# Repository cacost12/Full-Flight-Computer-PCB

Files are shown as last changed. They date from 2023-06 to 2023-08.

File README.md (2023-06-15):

<h1>Full Feature Flight Computer</h1>

<p><b>Current PCB Revision:</b> 1.0</p>
<p><b>PCB Part Number:</b> A0002</p>

<p>
The full feature flight computer supports the full range of amateur rocketry recovery and launch configurations 
such as dual-deploy parachute recovery, staging, IMU and barometric pressure sensor data logging, and redundant
parachute ejection. In addition to all the functionality of the base flight computer model, the full feature 
board includes two IMUs for low and high G data collection, and two auxiliary ignition ports for use with staging
ignition and/or redunant parachute ejection charges. 
 </p>

<b>Working Directory Structure:</b>
 
 <p>
cad: 3d models

doc: documentation

img: images of circuit/footprints for github display 
    
lib: libraries for schematic symbols and footprints
 
production: files needed for pcb fabrication, e.g. gerbers, profile, drill fi    le
 
sim: simulation files 
   
src: source design files, e.g. schematic and board files
 </p>

<h2>3D Model: </h2>
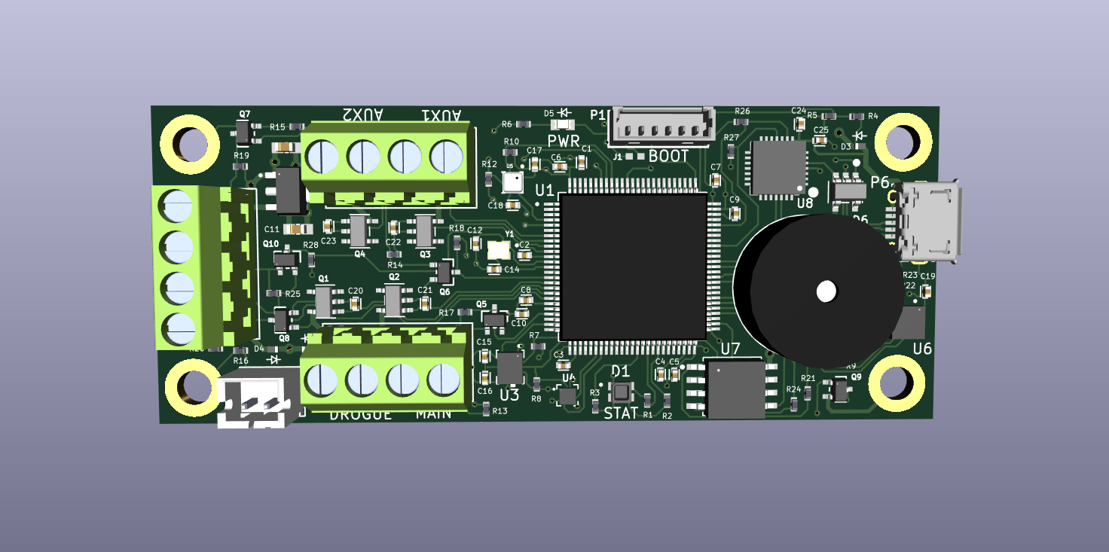
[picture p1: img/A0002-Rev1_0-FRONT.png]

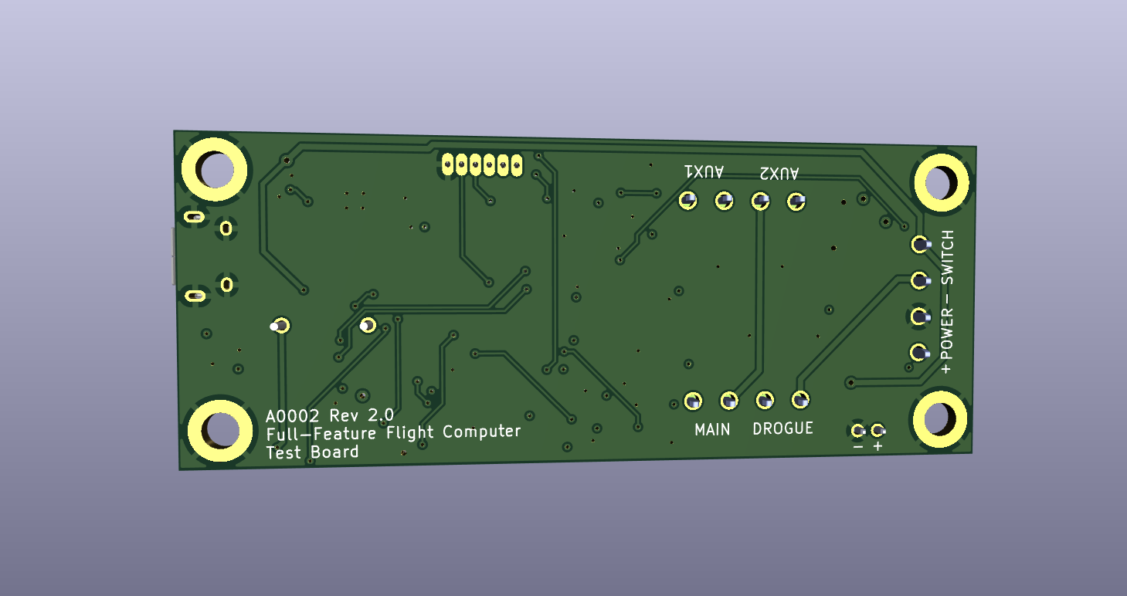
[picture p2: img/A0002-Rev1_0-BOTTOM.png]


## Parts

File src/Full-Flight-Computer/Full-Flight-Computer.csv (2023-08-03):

# | Reference | Qty | Value | Footprint | DNP
1 | BZ1 | 1 | AT-1438-TWT-R | Full-Flight-Computer:AT-1438-TWT-R
2 | C1 | 1 | 4.7uF | Full-Flight-Computer:CAP_0402
3 | C2, C3, C5, C6, C7, C8, C15, C16, C17, C18, C19, C25 | 12 | 0.1uF | Full-Flight-Computer:CAP_0402
4 | C4, C9 | 2 | 2.2uF | Full-Flight-Computer:CAP_0402
5 | C10, C20, C21, C22, C23, C24 | 6 | 1uF | Full-Flight-Computer:CAP_0402
6 | C11, C13 | 2 | 1uF | Full-Flight-Computer:CAP_0603
7 | C12, C14 | 2 | 8pF | Full-Flight-Computer:CAP_0402
8 | D1 | 1 | CLMVC-FKA-CL1D1L71BB7C3C3 | Full-Flight-Computer:CLMVC-FKA-CL1D1L71BB7C3C3
9 | D2, D3, D4 | 3 | PMEG3010AESBYL | Full-Flight-Computer:PMEG3010AESBYL
10 | D5 | 1 | LTST-C191KGKT | Full-Flight-Computer:LTST-C191KGKT
11 | D6 | 1 | SP0504BAHTG | Full-Flight-Computer:SP0504BAHTG
12 | H1, H2 | 2 | Mounting-Hole-4-40 | Full-Flight-Computer:MountingHole_4-40
13 | H3, H4 | 2 | Mounting-Hole | Full-Flight-Computer:MountingHole_4-40
14 | J1 | 1 | Jumper_NO | Full-Flight-Computer:Jumper-NO
15 | P1 | 1 | 0530470610 | Full-Flight-Computer:53047-0610
16 | P2 | 1 | B2B-PH-K-SLFSN_JST | Full-Flight-Computer:B2B-PH-K-SLFSN_JST
17 | P3, P5 | 2 | 1984659 | Full-Flight-Computer:1546551-4
18 | P4 | 1 | 1546551-4 | Full-Flight-Computer:1546551-4
19 | P6 | 1 | USB | Full-Flight-Computer:10118194-0001LF
20 | Q1, Q2, Q3, Q4 | 4 | QS5U17TR | Full-Flight-Computer:QS5U17TR
21 | Q5, Q6, Q7, Q8, Q9, Q10 | 6 | 2N7002W-7-F | Full-Flight-Computer:2N7002W-7-F
22 | R1, R2 | 2 | 82 | Full-Flight-Computer:RES_0402
23 | R3, R6 | 2 | 240 | Full-Flight-Computer:RES_0402
24 | R4 | 1 | 39k | Full-Flight-Computer:RES_0402
25 | R5, R7, R8, R9, R11, R17, R18, R19, R20, R21, R24, R27, R28 | 13 | 10k | Full-Flight-Computer:RES_0402
26 | R10, R12, R26 | 3 | 4.7k | Full-Flight-Computer:RES_0402
27 | R13, R14, R15, R16, R22, R25 | 6 | 100k | Full-Flight-Computer:RES_0402
28 | R23 | 1 | 200k | Full-Flight-Computer:RES_0402
29 | U1 | 1 | STM32H750VBTx | Full-Flight-Computer:STM32H750VBT6
30 | U2 | 1 | AP7370-33Y-13 | Full-Flight-Computer:AP7370-33Y-13
31 | U3 | 1 | BMI323 | Full-Flight-Computer:BMI323
32 | U4 | 1 | BMM150 | Full-Flight-Computer:BMM150
33 | U5 | 1 | BMP390 | Full-Flight-Computer:BMP390
34 | U6 | 1 | H3LIS100DLTR | Full-Flight-Computer:H3LIS100DLTR
35 | U7 | 1 | SST25VF040B-50-4I-S2AE-T | Full-Flight-Computer:SST25VF040B-50-4I-S2AE-T
36 | U8 | 1 | CP2102-GMR(QFN28) | Full-Flight-Computer:CP2012-GMR
37 | Y1 | 1 | ECS-240-18-33-JGN-TR | Full-Flight-Computer:ECS-240-12-37B-CKY-TR

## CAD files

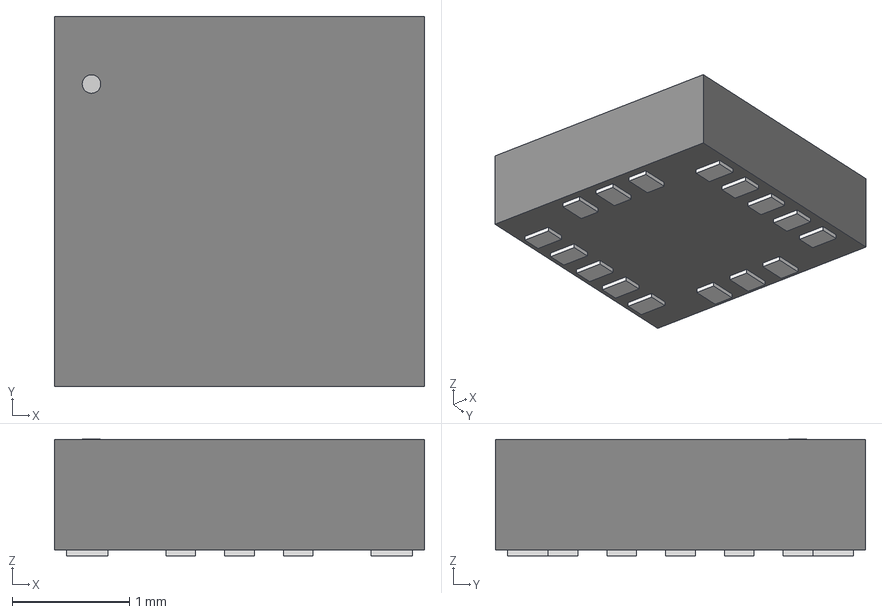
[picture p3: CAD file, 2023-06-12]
CAD/3Dfiles/H3LIS100DLTR.step
3.15 x 3.15 x 0.993 mm

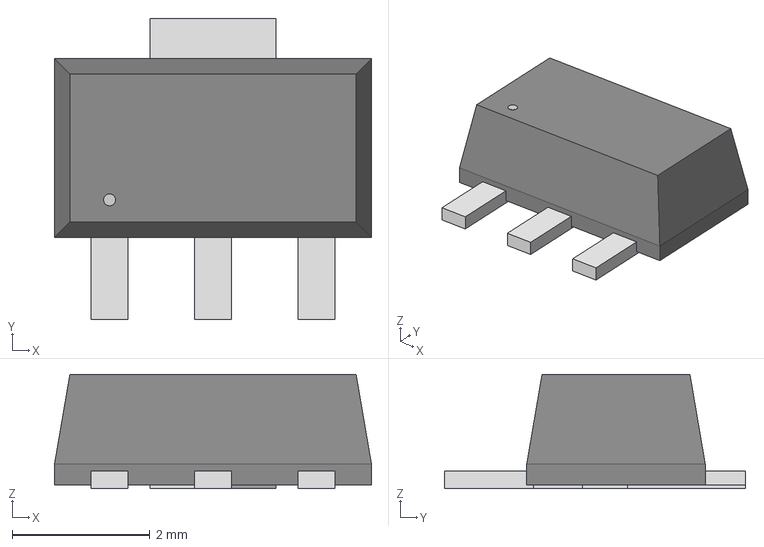
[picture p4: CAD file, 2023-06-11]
CAD/3Dfiles/AP7370-33Y-13.step
4.60 x 4.37 x 1.65 mm

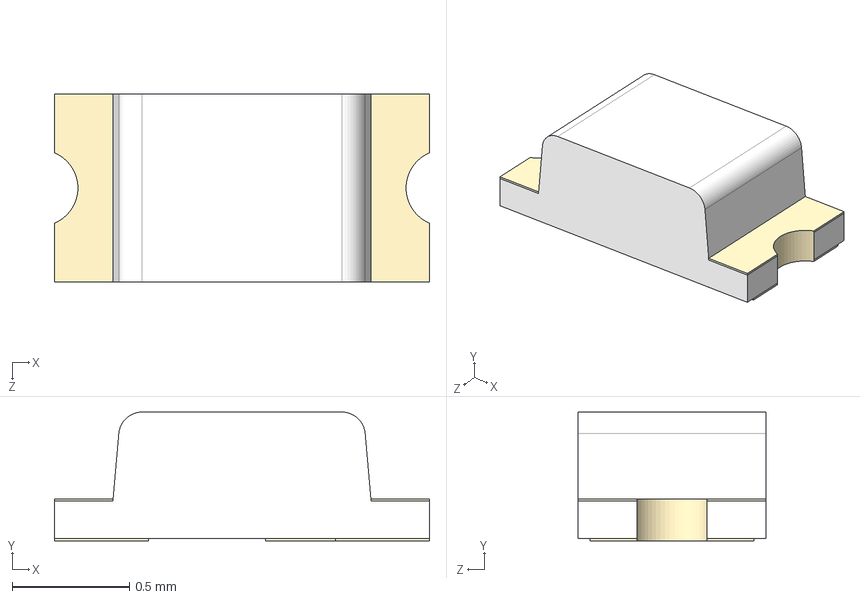
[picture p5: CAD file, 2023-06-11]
CAD/3Dfiles/LTST-C191KGKT.step
1.60 x 0.55 x 0.8 mm

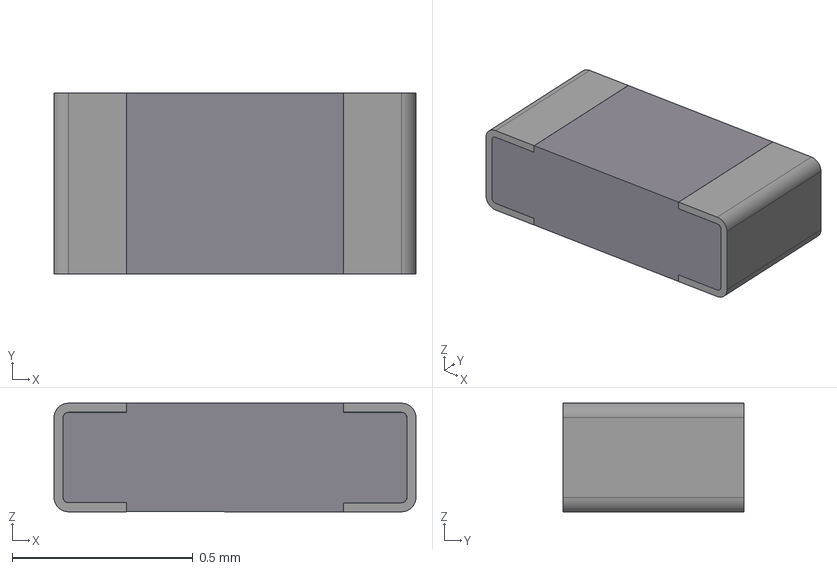
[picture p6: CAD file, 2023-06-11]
CAD/3Dfiles/RES_0402.step
1.00 x 0.5 x 0.3 mm
Chip_001

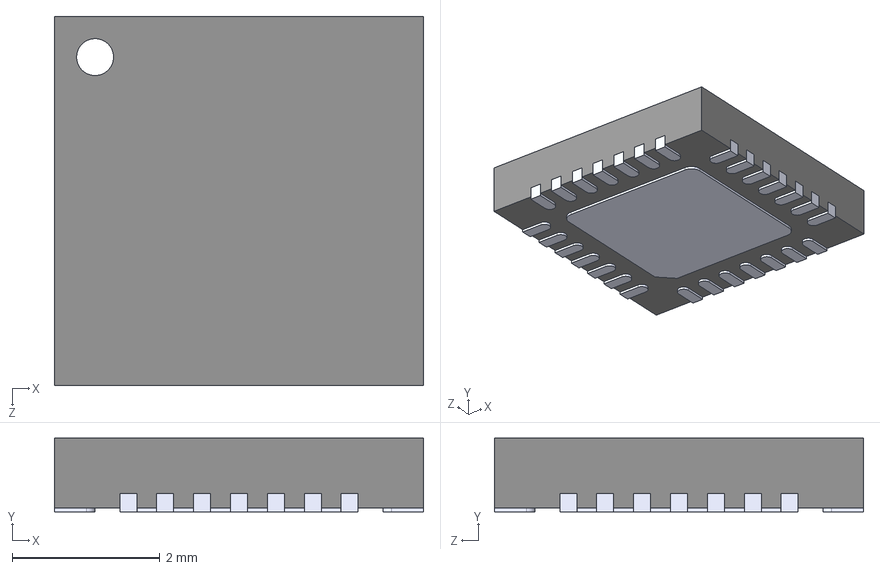
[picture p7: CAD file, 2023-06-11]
CAD/3Dfiles/CP2102.step
5.00 x 1.00 x 5.00 mm

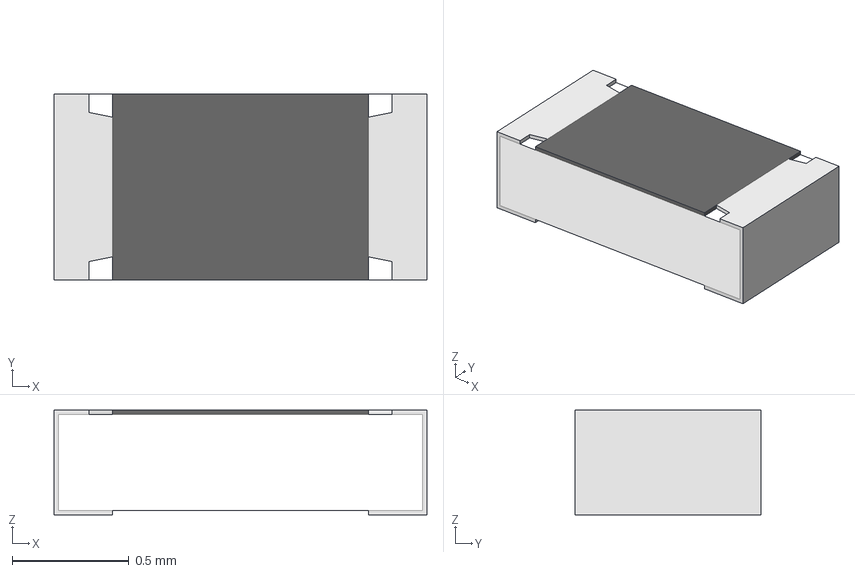
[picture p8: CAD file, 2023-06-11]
CAD/3Dfiles/RES_0603.step
1.60 x 0.8 x 0.45 mm

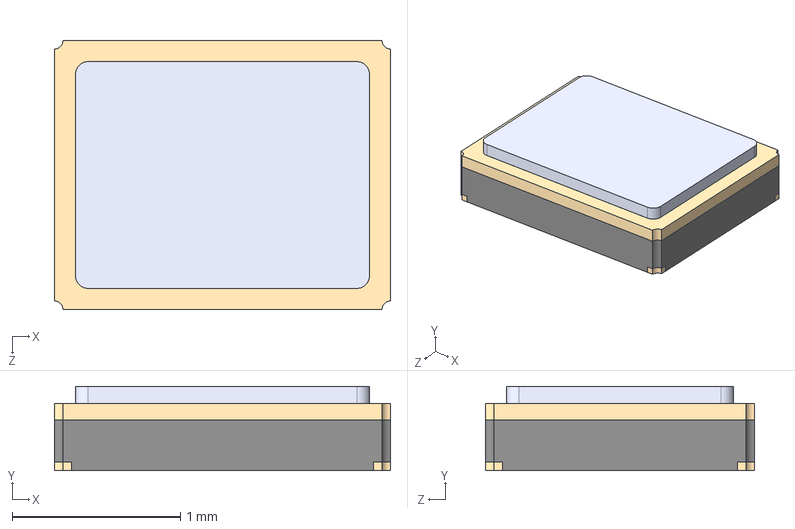
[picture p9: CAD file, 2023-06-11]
CAD/3Dfiles/ECS-240-12-37B-CKY-TR.step
2.00 x 0.5 x 1.60 mm

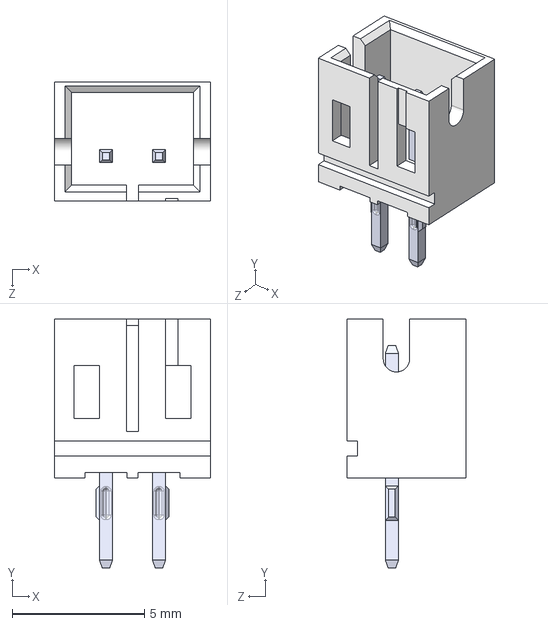
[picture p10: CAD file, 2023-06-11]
CAD/3Dfiles/B2B_PH_K_S_LF__SN_.step
5.90 x 9.40 x 4.50 mm

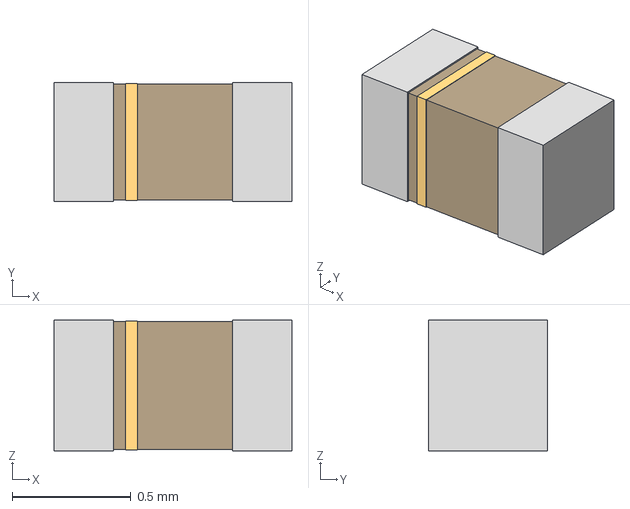
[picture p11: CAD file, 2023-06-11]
CAD/3Dfiles/CAP_0402.step
1.00 x 0.5 x 0.55 mm

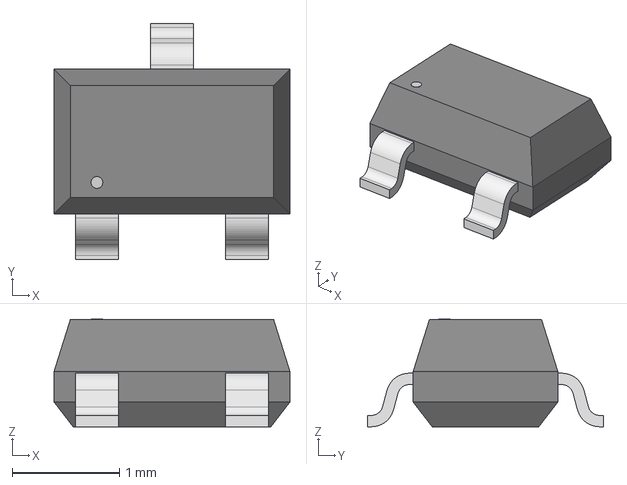
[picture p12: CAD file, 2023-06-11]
CAD/3Dfiles/2N7002W-7-F.step
2.20 x 2.20 x 1.00 mm

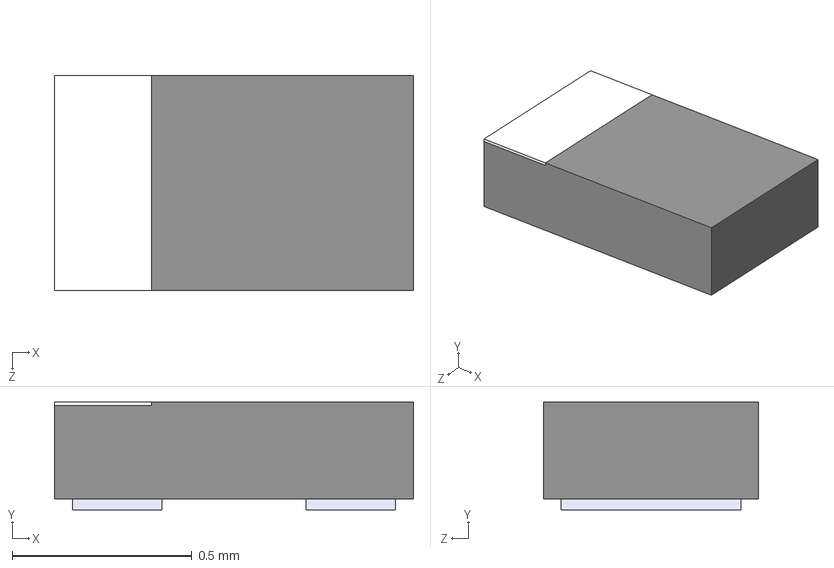
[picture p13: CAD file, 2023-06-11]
CAD/3Dfiles/PMEG3010AESBYL.step
1.00 x 0.3 x 0.6 mm

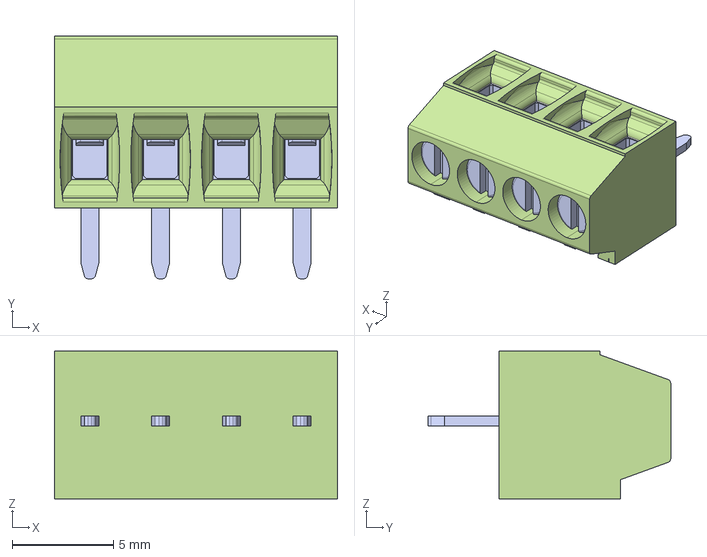
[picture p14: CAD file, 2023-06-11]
CAD/3Dfiles/1546551-4.step
14.0 x 12.0 x 7.30 mm

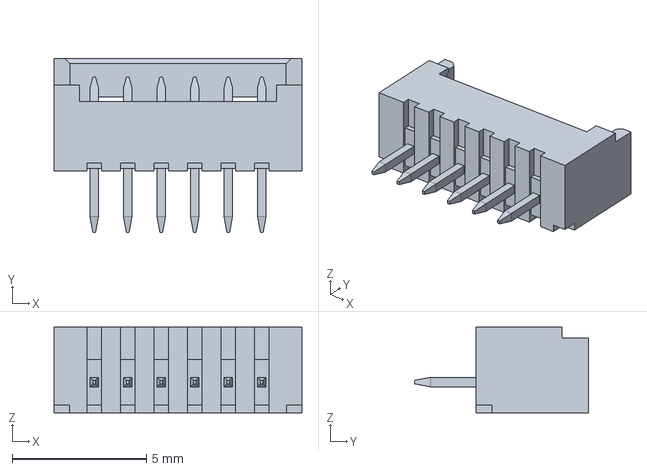
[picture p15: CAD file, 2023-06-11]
CAD/3Dfiles/530470610.stp
9.25 x 6.50 x 3.20 mm

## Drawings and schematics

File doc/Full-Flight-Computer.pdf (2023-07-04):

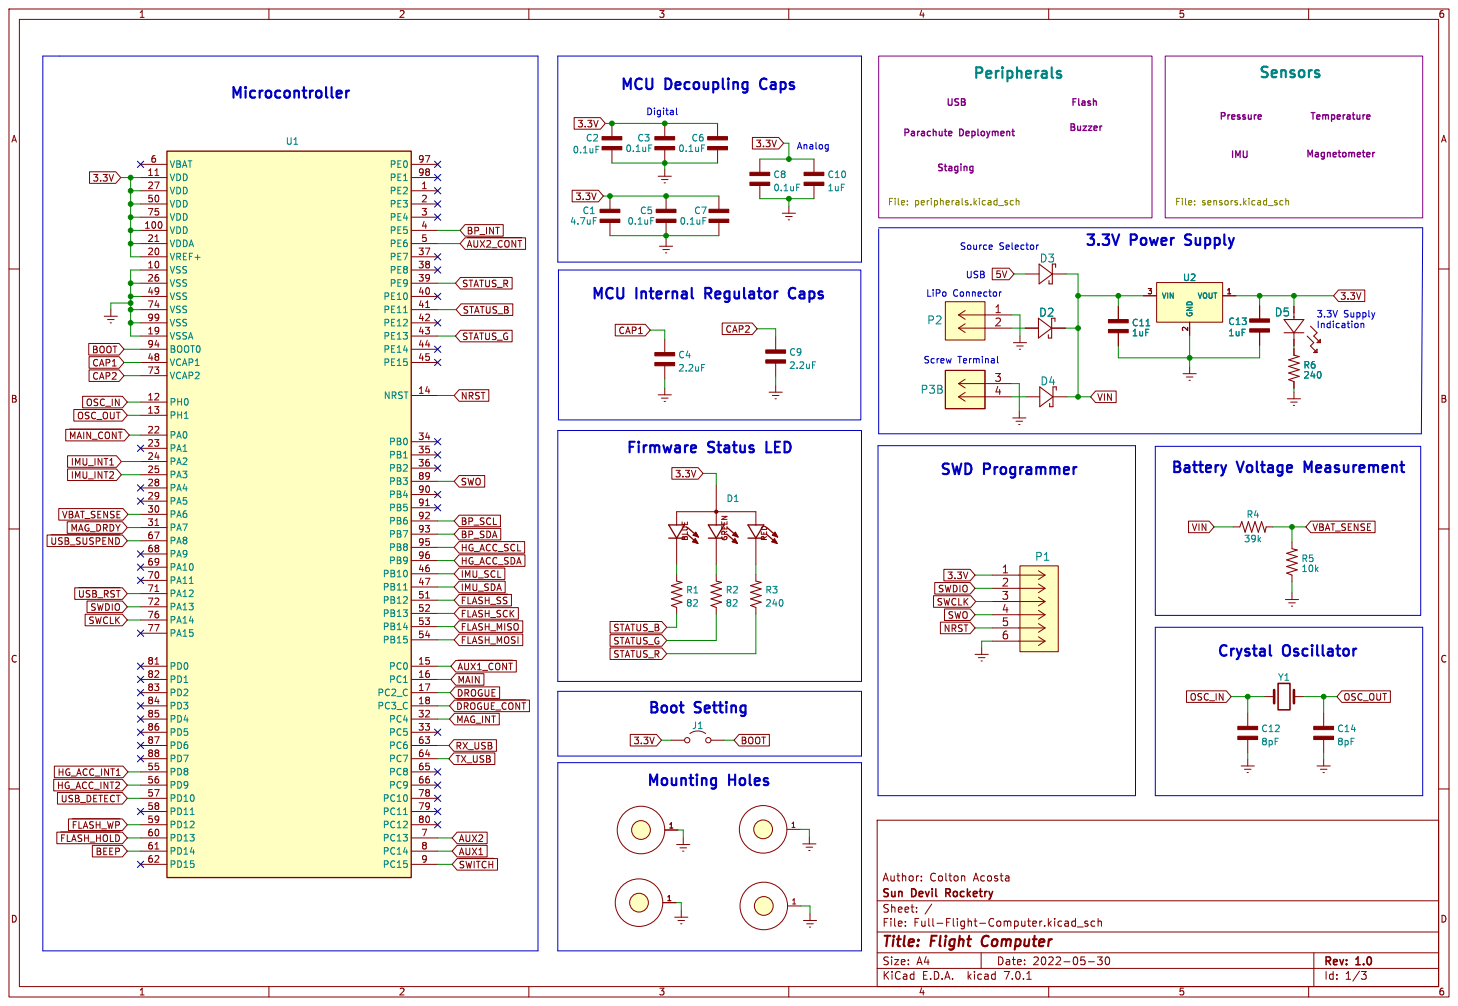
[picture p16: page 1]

Indication Battery Voltage Measurement USB

MCU Internal Regulator Caps

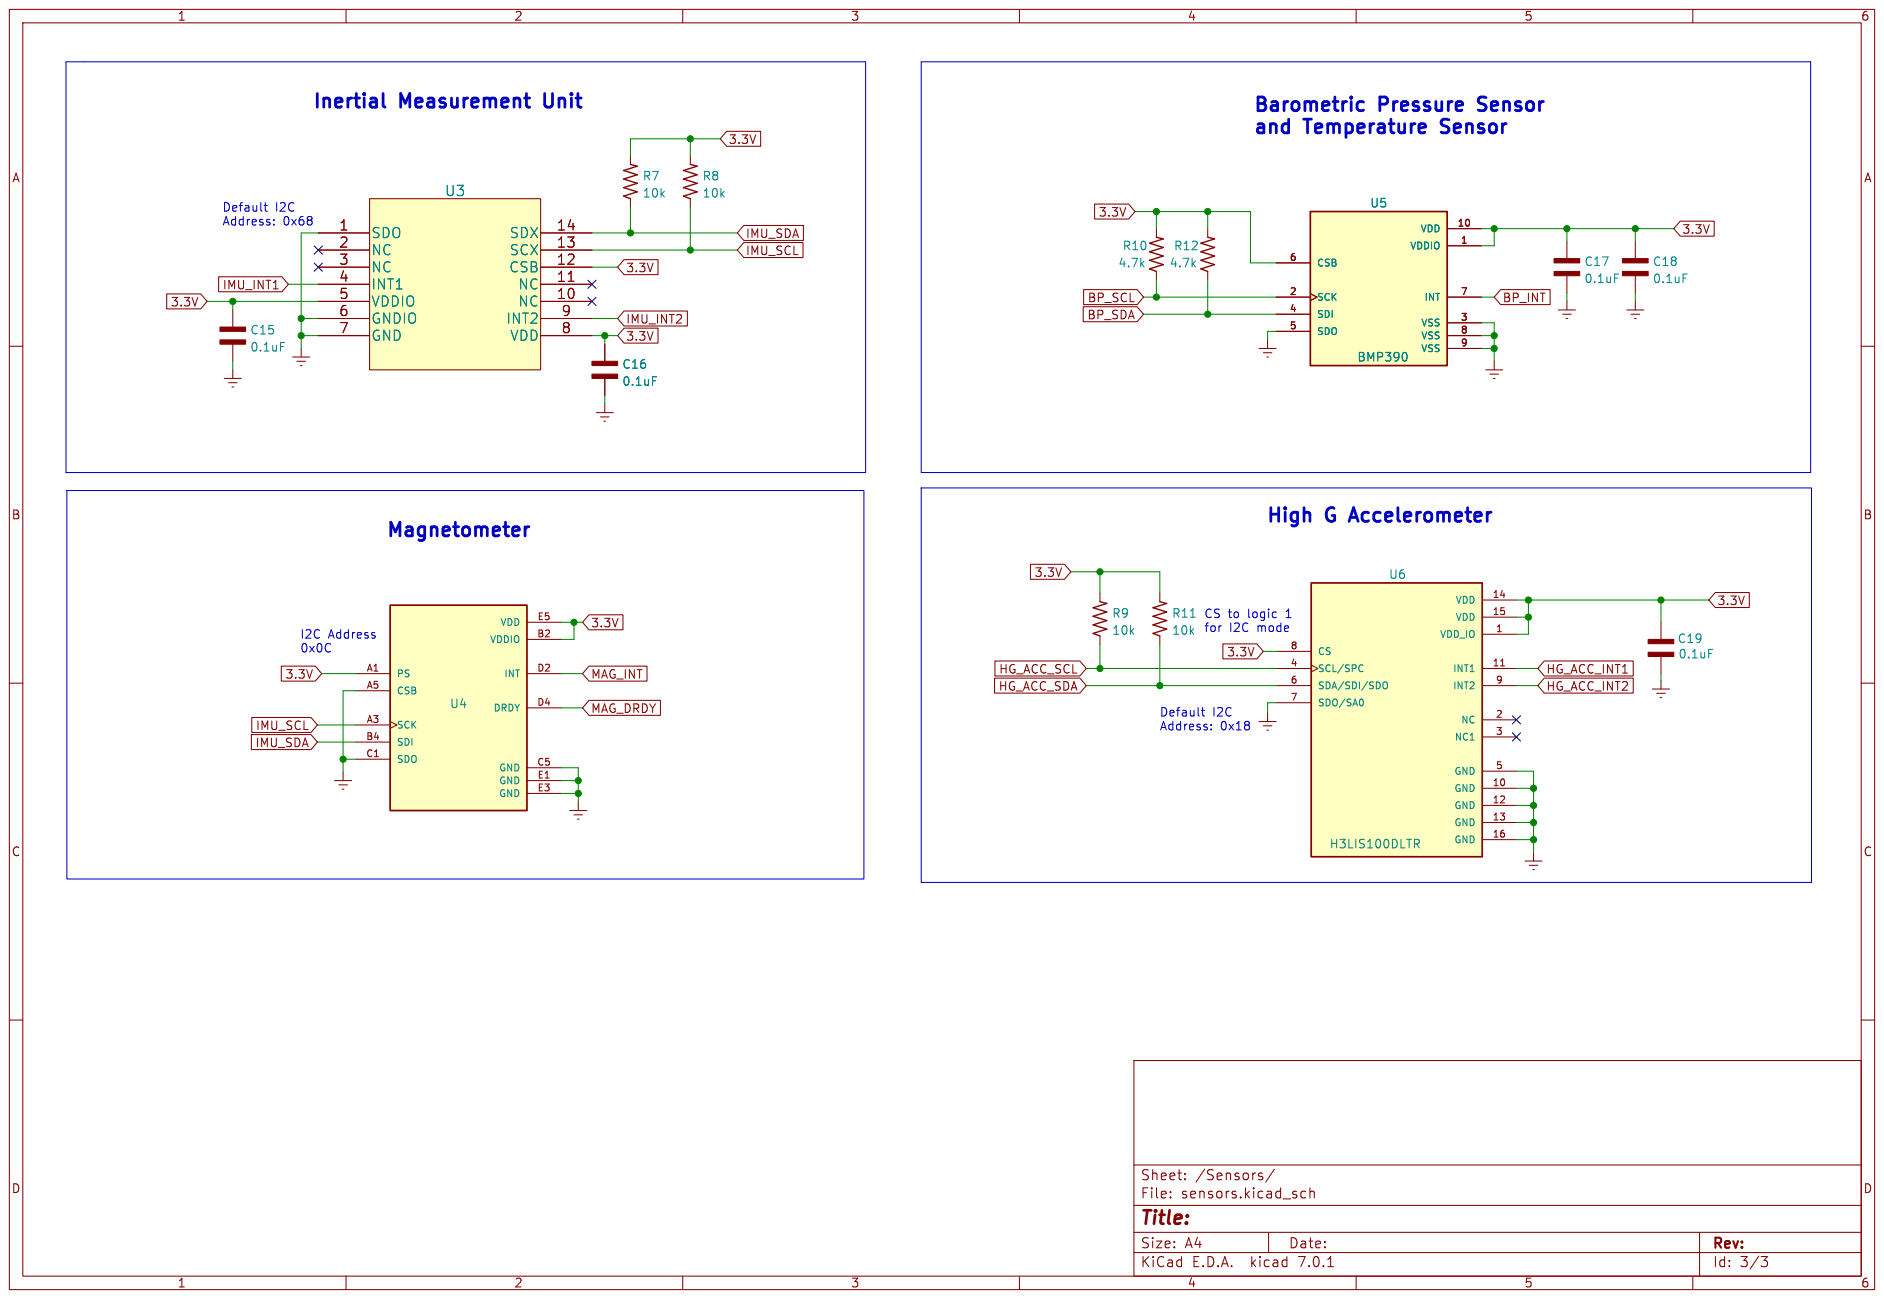
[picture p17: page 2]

Id: 3/3 Title: File: sensors.kicad_sch Sheet: /Sensors/

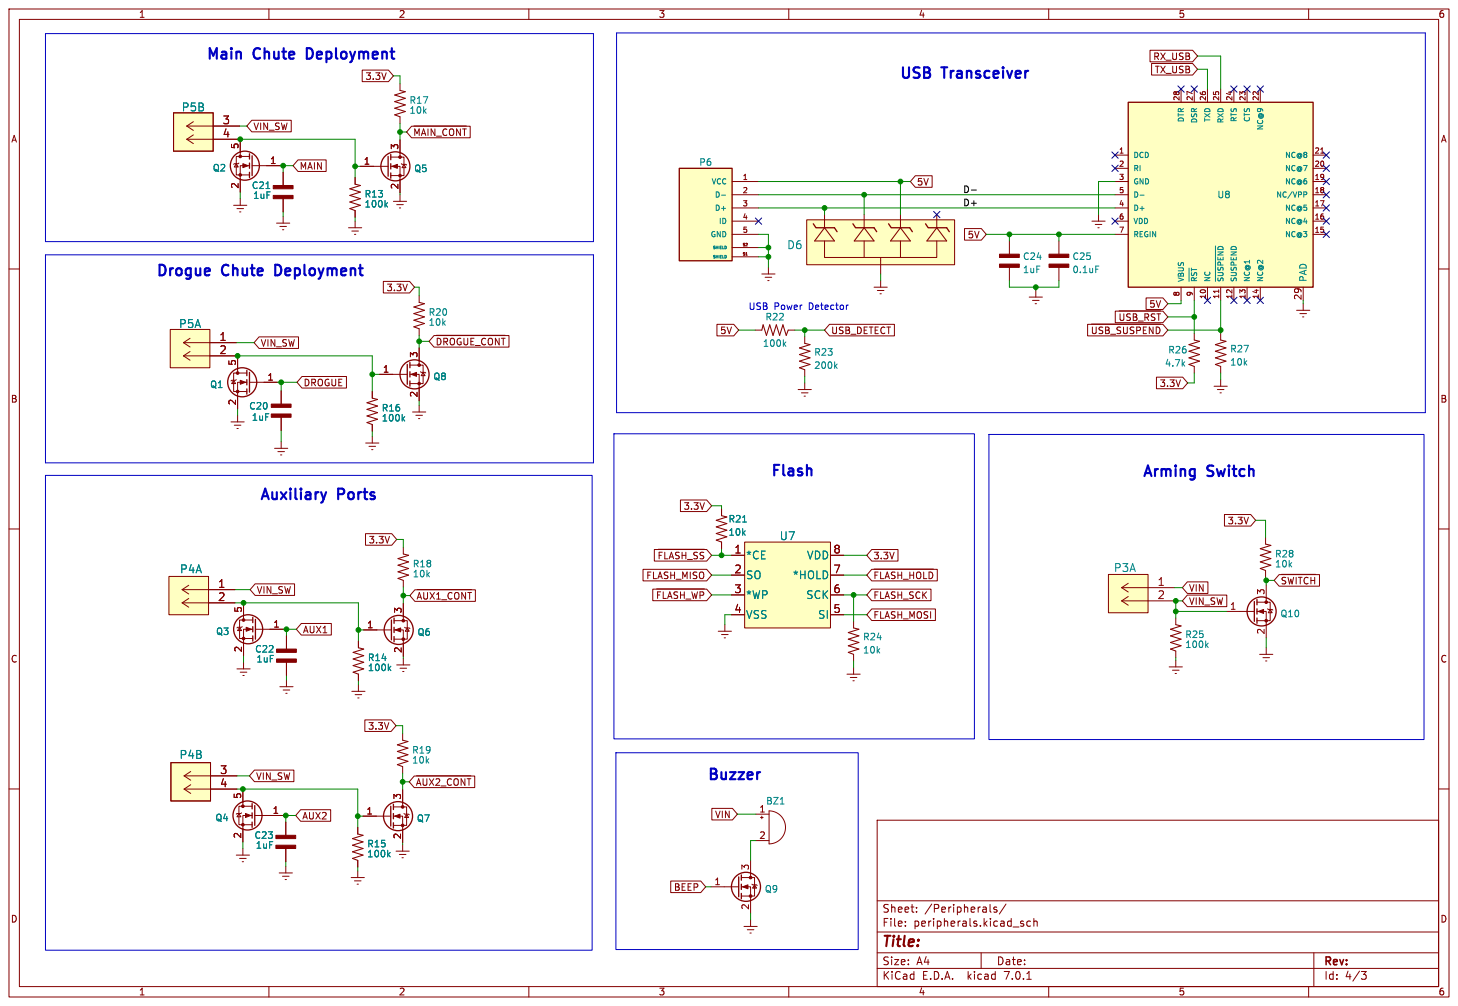
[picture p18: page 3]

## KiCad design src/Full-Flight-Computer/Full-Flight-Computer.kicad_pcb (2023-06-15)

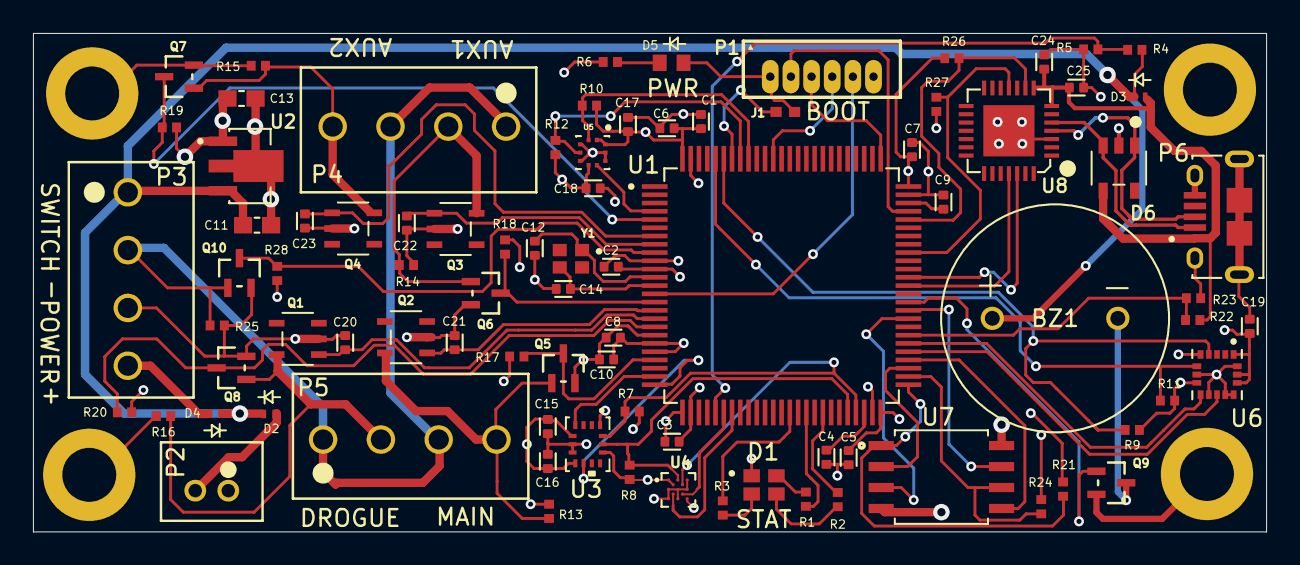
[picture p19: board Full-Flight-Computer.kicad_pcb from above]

Board: 4 copper layers, 74.7 x 30.2 mm, 90 parts (0 on the bottom side), 65 nets.

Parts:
BZ1: AT-1438-TWT-R
C1: 4.7uF; CAP_0402
C2, C3, C5, C6, C7, C8, C15, C16, C17, C18, C19, C25: 0.1uF; CAP_0402
C4, C9: 2.2uF; CAP_0402
C10, C20, C21, C22, C23, C24: 1uF; CAP_0402
C11, C13: 1uF; CAP_0603
C12, C14: 8pF; CAP_0402
D1: CLMVC-FKA-CL1D1L71BB7C3C3
D2, D3, D4: PMEG3010AESBYL
D5: LTST-C191KGKT
D6: SP0504BAHTG
H1, H2: Mounting-Hole-4-40; MountingHole_4-40
H3, H4: Mounting-Hole; MountingHole_4-40
J1: Jumper_NO; Jumper-NO
P1: 0530470610; 53047-0610
P2: B2B-PH-K-SLFSN_JST
P3, P5: 1984659; 1546551-4
P4: 1546551-4
P6: USB; 10118194-0001LF
Q1, Q2, Q3, Q4: QS5U17TR
Q5, Q6, Q7, Q8, Q9, Q10: 2N7002W-7-F
R1, R2: 82; RES_0402
R3, R6: 240; RES_0402
R4: 39k; RES_0402
R5, R7, R8, R9, R11, R17, R18, R19, R20, R21, R24, R27, R28: 10k; RES_0402
R10, R12, R26: 4.7k; RES_0402
R13, R14, R15, R16, R22, R25: 100k; RES_0402
R23: 200k; RES_0402
U1: STM32H750VBTx; STM32H750VBT6
U2: AP7370-33Y-13
U3: BMI323
U4: BMM150
U5: BMP390
U6: H3LIS100DLTR
U7: SST25VF040B-50-4I-S2AE-T
U8: CP2102-GMR(QFN28); CP2012-GMR
Y1: ECS-240-18-33-JGN-TR; ECS-240-12-37B-CKY-TR

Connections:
3.3V: C1.1, C2.1, C3.1, C5.1, C6.1, C7.1, C8.1, C10.1, C13.1, C15.1, C16.1, C17.1, C18.1, C19.1, D1.1, D5.2, J1.1 (A), P1.1, R7.2, R8.2, R9.2, R10.2, R11.2, R12.2, R17.2, R18.2, R19.2, R20.2, R21.2, R26.1, R28.2, U1.11 (VDD), U1.20 (VREF+), U1.21 (VDDA), U1.27 (VDD), U1.50 (VDD), U1.75 (VDD), U1.100 (VDD), U2.1 (VOUT), U3.5 (VDDIO), U3.8 (VDD), U3.12 (CSB), U4.A1 (PS), U4.B2 (VDDIO), U4.E5 (VDD), U5.1 (VDDIO), U5.6 (CSB), U5.10 (VDD), U6.1 (VDD_IO), U6.8 (CS), U6.14 (VDD), U6.15 (VDD), U7.8 (VDD)
5V: C24.1, C25.1, D3.A, D6.4, P6.1 (VCC), R22.2, U8.7 (REGIN), U8.8 (VBUS)
/Peripherals/D+: D6.1, P6.3 (D+), U8.4 (D+)
/Peripherals/D-: D6.3, P6.2 (D-), U8.5 (D-)
AUX1: C22.1, Q3.1 (G), U1.8 (PC14)
AUX2: C23.1, Q4.1 (G), U1.7 (PC13)
BEEP: Q9.1 (G), U1.61 (PD14)
BOOT: J1.2 (B), U1.94 (BOOT0)
BP_INT: U1.4 (PE5), U5.7 (INT)
BP_SCL: R10.1, U1.92 (PB6), U5.2 (SCK)
BP_SDA: R12.1, U1.93 (PB7), U5.4 (SDI)
CAP1: C4.1, U1.48 (VCAP1)
CAP2: C9.1, U1.73 (VCAP2)
DROGUE: C20.1, Q1.1 (G), U1.17 (PC2_C)
Earth: C1.2, C2.2, C3.2, C4.2, C5.2, C6.2, C7.2, C8.2, C9.2, C10.2, C11.2, C12.2, C13.2, C14.2, C15.2, C16.2, C17.2, C18.2, C19.2, C20.2, C21.2, C22.2, C23.2, C24.2, C25.2, D6.2, H1.1, H2.1, H3.1, H4.1, P1.6, P2.1 (5), P3.3 (5), P6.5 (GND), P6.S1 (SHIELD), P6.S2 (SHIELD), Q1.2 (S), Q2.2 (S), Q3.2 (S), Q4.2 (S), Q5.2 (S), Q6.2 (S), Q7.2 (S), Q8.2 (S), Q9.2 (S), Q10.2 (S), R5.1, R6.1, R13.1, R14.1, R15.1, R16.1, R23.1, R24.1, R25.1, R27.1, U1.10 (VSS), U1.19 (VSSA), U1.26 (VSS), U1.49 (VSS), U1.74 (VSS), U1.99 (VSS), U2.2 (GND), U3.1 (SDO), U3.6 (GNDIO), U3.7 (GND), U4.A5 (CSB), U4.C1 (SDO), U4.C5 (GND), U4.E1 (GND), U4.E3 (GND), U5.3 (VSS), U5.5 (SDO), U5.8 (VSS), U5.9 (VSS), U6.5 (GND), U6.7 (SDO/SA0), U6.10 (GND), U6.12 (GND), U6.13 (GND), U6.16 (GND), U7.4 (VSS), U8.3 (GND), U8.29 (PAD)
FLASH_MISO: U1.53 (PB14), U7.2 (SO)
FLASH_MOSI: U1.54 (PB15), U7.5 (SI)
FLASH_SCK: R24.2, U1.52 (PB13), U7.6 (SCK)
HG_ACC_INT1: U1.55 (PD8), U6.11 (INT1)
HG_ACC_INT2: U1.56 (PD9), U6.9 (INT2)
HG_ACC_SCL: R9.1, U1.95 (PB8), U6.4 (SCL/SPC)
HG_ACC_SDA: R11.1, U1.96 (PB9), U6.6 (SDA/SDI/SDO)
IMU_INT1: U1.24 (PA2), U3.4 (INT1)
IMU_INT2: U1.25 (PA3), U3.9 (INT2)
MAG_DRDY: U1.31 (PA7), U4.D4 (DRDY)
MAG_INT: U1.32 (PC4), U4.D2 (INT)
MAIN: C21.1, Q2.1 (G), U1.16 (PC1)
NRST: P1.5, U1.14 (NRST)
unnamed: BZ1.2 (+), Q9.3 (D)
unnamed: D1.2, R1.2
unnamed: D1.3, R2.2
unnamed: D1.4, R3.2
unnamed: D5.1, R6.2
unnamed: D2.A, P2.2 (6)
unnamed: D4.A, P3.4 (6)
unnamed: P4.2 (6), Q3.5 (D), Q6.1 (G), R14.2
unnamed: P4.4 (6), Q4.5 (D), Q7.1 (G), R15.2
unnamed: P5.2 (6), Q1.5 (D), Q8.1 (G), R16.2
unnamed: P5.4 (6), Q2.5 (D), Q5.1 (G), R13.2
OSC_IN: C12.1, U1.12 (PH0), Y1.1
OSC_OUT: C14.1, U1.13 (PH1), Y1.3
RX_USB: U1.63 (PC6), U8.25 (RXD)
SCL: R8.1, U1.46 (PB10), U3.13 (SCX), U4.A3 (SCK)
SDA: R7.1, U1.47 (PB11), U3.14 (SDX), U4.B4 (SDI)
STATUS_B: R1.1, U1.41 (PE11)
STATUS_G: R2.1, U1.43 (PE13)
STATUS_R: R3.1, U1.39 (PE9)
SWCLK: P1.3, U1.76 (PA14)
SWDIO: P1.2, U1.72 (PA13)
SWO: P1.4, U1.89 (PB3)
TX_USB: U1.64 (PC7), U8.26 (TXD)
USB_DETECT: R22.1, R23.2, U1.57 (PD10)
VBAT_SENSE: R4.2, R5.2, U1.30 (PA6)
VIN: BZ1.1 (-), C11.1, D2.C, D3.C, D4.C, P3.1 (5), R4.1, U2.3 (VIN)
VIN_SW: P3.2 (6), P4.1 (5), P4.3 (5), P5.1 (5), P5.3 (5), Q10.1 (G), R25.2
~AUX1_CONT: Q6.3 (D), R18.1, U1.15 (PC0)
~AUX2_CONT: Q7.3 (D), R19.1, U1.5 (PE6)
~DROGUE_CONT: Q8.3 (D), R20.1, U1.18 (PC3_C)
~FLASH_HOLD: U1.60 (PD13), U7.7 (*HOLD)
~FLASH_SS: R21.1, U1.51 (PB12), U7.1 (*CE)
~FLASH_WP: U1.59 (PD12), U7.3 (*WP)
~MAIN_CONT: Q5.3 (D), R17.1, U1.22 (PA0)
~SWITCH: Q10.3 (D), R28.1, U1.9 (PC15)
~USB_RST: R26.2, U1.71 (PA12), U8.9 (~RST)
~USB_SUSPEND: R27.2, U1.67 (PA8), U8.11 (~SUSPEND)

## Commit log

2023-06-11 removed old CAD files
2023-06-11 removed old schematic and gerber files
    [Flight-Computer-B_Cu.gbr, Flight-Computer-B_Mask.gbr, Flight-Computer-B_Paste.gbr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]
2023-06-11 renamed project file to full-flight-computer
    [Connectors.kicad_sch, Connectors.sch, Flash_SD.kicad_sch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]
2023-06-11 added kicad backup directories to gitignore
2023-06-11 created new footprint library
    [142-0701-801.STEP, 1546551-4.step, 1984659.stp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]
2023-06-11 removed extra sections from schematic
    [Full-Flight-Computer.kicad_sch, peripherals.kicad_sch, sensors.kicad_sch]
2023-06-12 fixed all schematic symbol links to link to correct lib file
    [Full-Flight-Computer.kicad_sch, peripherals.kicad_sch, sensors.kicad_sch]
2023-06-12 added auxiliary ports for staging/redundant ejection charges
    [Full-Flight-Computer.kicad_sch, peripherals.kicad_sch, sensors.kicad_sch]
2023-06-12 added high G accelerometer to lib files
    [H3LIS100DLTR.step]
2023-06-12 implemented high G accelerometer schematic
    [Full-Flight-Computer.kicad_sch, sensors.kicad_sch]
2023-06-12 redid component designators and updated BOM
    [Full-Flight-Computer.kicad_sch, peripherals.kicad_sch, sensors.kicad_sch]
2023-06-14 placed all components on test board
    [Full-Flight-Computer.kicad_pcb, Full-Flight-Computer.kicad_sch, sensors.kicad_sch]
2023-06-15 completed initial layout
    [Full-Flight-Computer.kicad_pcb, Full-Flight-Computer.kicad_sch, peripherals.kicad_sch]
2023-06-15 resolved all DRC errors
    [Full-Flight-Computer.kicad_pcb]
2023-06-15 moved BP_INT signal to new MCU pin to avoid EXTI collision with IMU interrupt signal
    [Full-Flight-Computer.kicad_pcb, Full-Flight-Computer.kicad_sch]
2023-06-15 added fabrication outputs
    [Full-Flight-Computer-B_Cu.gbr, Full-Flight-Computer-B_Mask.gbr, Full-Flight-Computer-B_Paste.gbr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]
2023-06-15 added PCB images to README
2023-07-04 add IMU prefix to IMU SDA and SCL labels
    [Full-Flight-Computer.kicad_sch, sensors.kicad_sch]
2023-08-03 generated BOM from shcematic
    [Full-Flight-Computer.csv]

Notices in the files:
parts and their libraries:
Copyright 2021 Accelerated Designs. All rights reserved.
